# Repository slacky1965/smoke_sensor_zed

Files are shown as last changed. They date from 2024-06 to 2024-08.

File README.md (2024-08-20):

# Smoke Sensor Zigbee Telink TLSR8258 (E-BYTE E180-Z5812SP)

[Repository smoke_sensor_zed](https://github.com/slacky1965/smoke_sensor_zed)

* [Описание](#description)
* [Железо](#hardware)
* [Софт](#software)  
* [Принцип работы](#firmware)
* [Настройка](#settings)
* [Home Assistant](#home_assistant)
* [Alisa](#alisa)

---

## <a id="description">Описание</a>

* Сделано в виде дополнительной платы к заводскому пожарному дымовому извещателю [Рубеж ИП 212-50М2](https://yandex.ru/search?text=%D0%A0%D1%83%D0%B1%D0%B5%D0%B6+%D0%98%D0%9F+212-50%D0%9C2&lr=213).
* Изменяет статус ALARM1 в IAS при обнаружении дыма.
* Изменяет статус TAMPER в IAS при снятии извещателя с крепежной пластины.
* Посылает команду On-Off (Off-On или Toggle, в зависимости от выбранных настроек) при обнаружении дыма.
* Сохраняет настройки в энергонезависимой памяти модуля.
* Передает показания по сети Zigbee.
* Кластер On_Off имеет возможность напрямую подключаться к исполнительному устройству минуя координатор.
* Взаимодейстивие с "умными домами" через zigbee2mqtt.
* Первоначальная настройка происходит через web-интерфейс zigbee2mqtt.
* Подключиться к сети zigbee - удерживать кнопку на плате устройства более 5 секунд.
* Покинуть сеть zigbee - удерживать кнопку на плате устройства более 5 секунд.
* Сделать restart модуля - нажать кнопку 5 раз.
* При одиночном нажатии кнопки модуль просыпается и высылает отчеты.

---

## <a id="hardware">Железо</a>

В проекте используется модуль от компании E-BYTE на чипе TLSR8258F512ET32 - E180-Z5812SP.

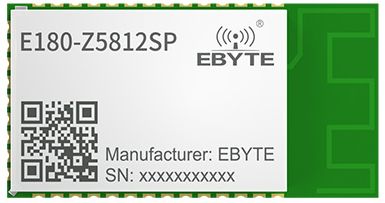
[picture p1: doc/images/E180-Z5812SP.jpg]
E-BYTE E180-Z5812SP


Испытывалось все на вот такой плате совместной разработки (спасибо [Олегу](https://t.me/Novgorod73))

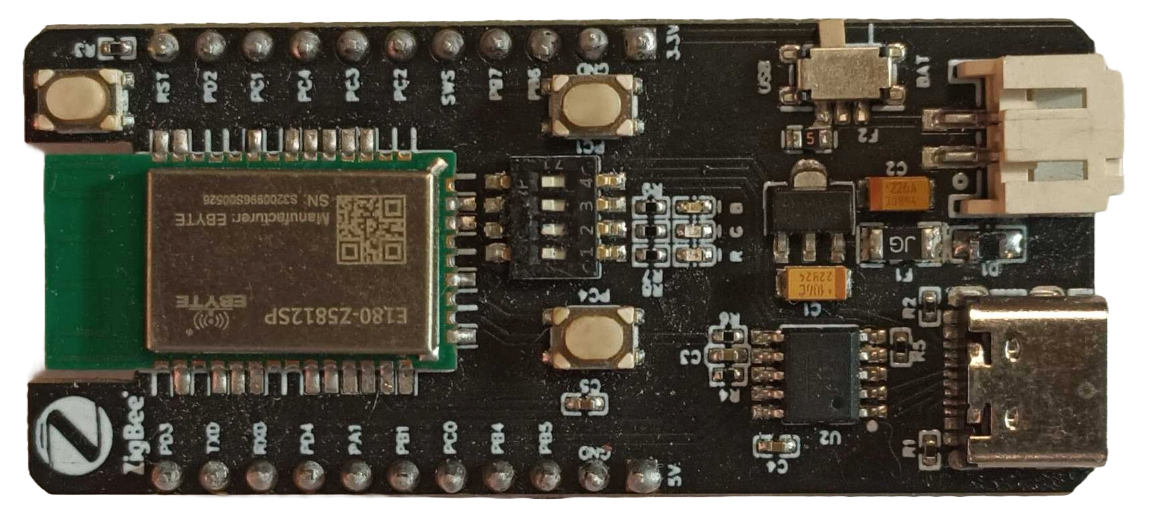
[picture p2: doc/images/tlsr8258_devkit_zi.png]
TLSR8258 devkit_zi


---

**Схема**

Схема изделия.

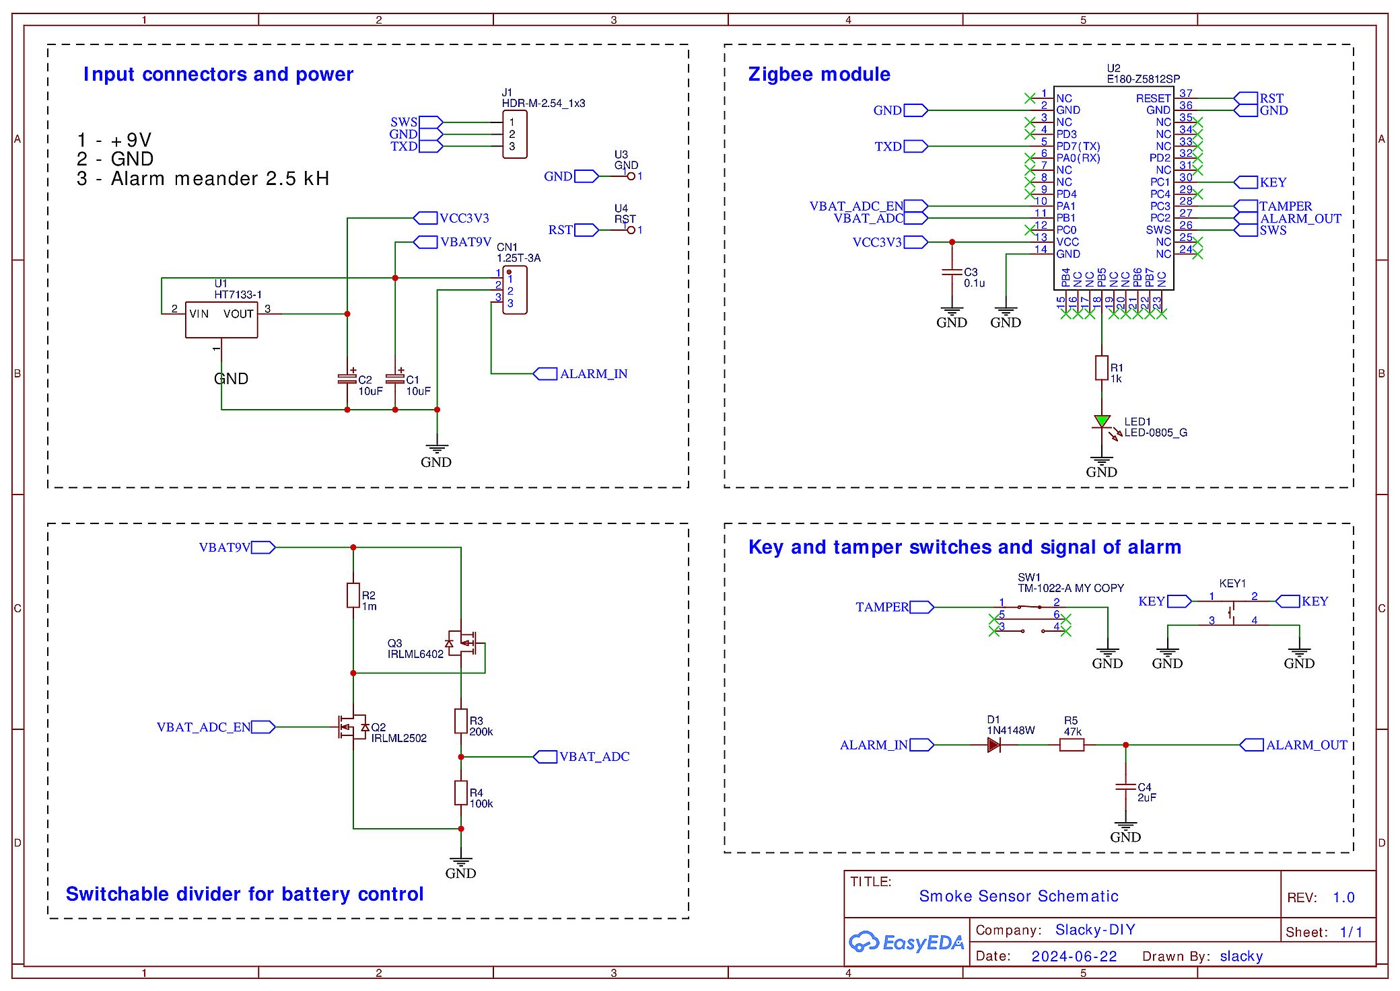
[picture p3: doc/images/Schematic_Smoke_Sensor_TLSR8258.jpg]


**Плата**

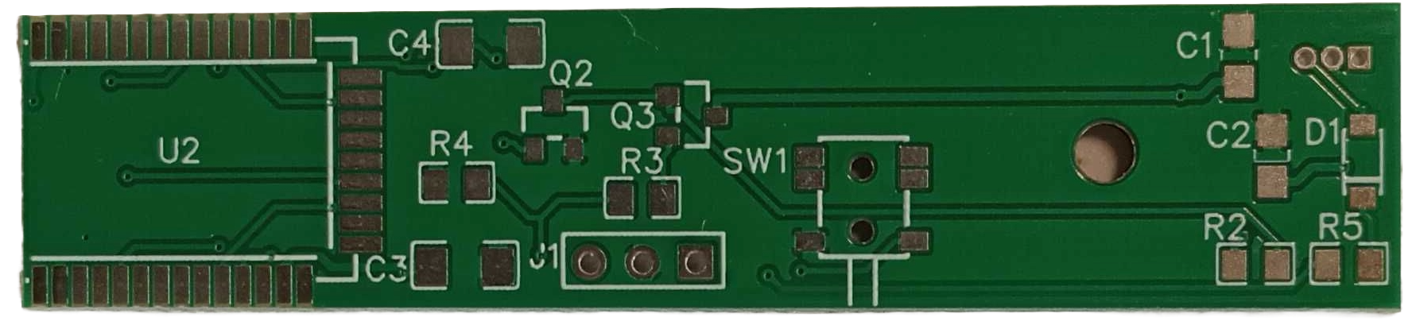
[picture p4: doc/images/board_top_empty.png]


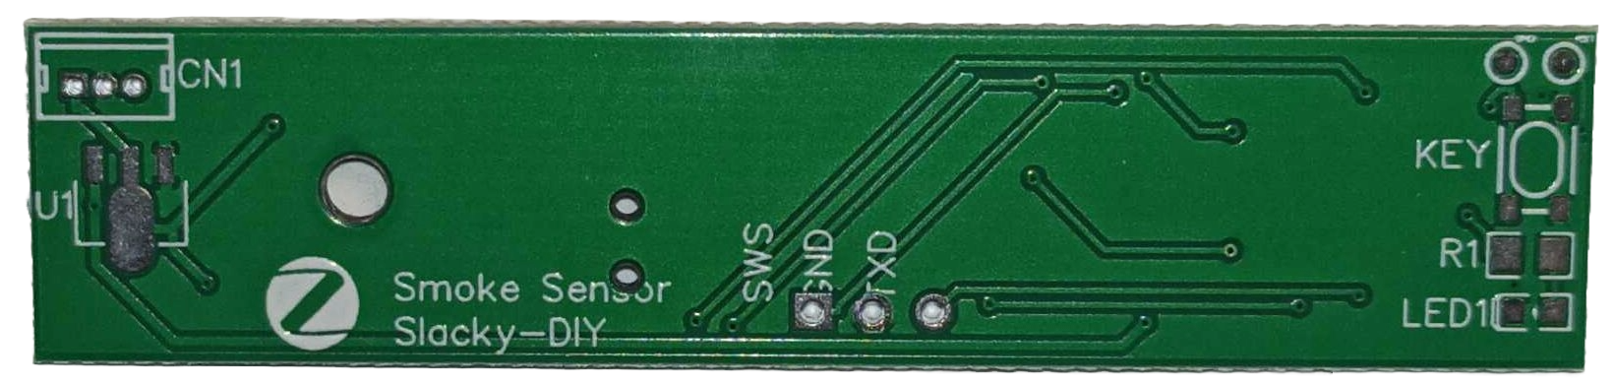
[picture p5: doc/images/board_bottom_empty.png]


На гребенку выведены следующие пины модуля

* SWS, GND - для заливки в модуль прошивки
* TXD-DBG - на всякий случай, вдруг кому-то пригодится для отладки.

[Ссылки на проект в easyeda](https://oshwlab.com/slacky/smoke_sensor_tlsr8258)

Детали, напечатанные на 3D принтере.

[Прокладка для платы](https://raw.githubusercontent.com/slacky1965/smoke_sensor_zed/main/doc/3D/Pad.STL)

[Кронштейн платы](https://raw.githubusercontent.com/slacky1965/smoke_sensor_zed/main/doc/3D/Support_new.STL)

Плата zigbee подключается к заводскому модулю следующим образом - 

* Красный провод (1 контакт разъема CN1) - к +9v - контакт 1 на плате извещателя.
* Черный провод (2 контакт разъема CN1) - к -9v (или земля) - контакт 2 на плате извещателя.
* Желтый провод (3 контакт раъема CN1) - контакт К1 на плате извещателя.

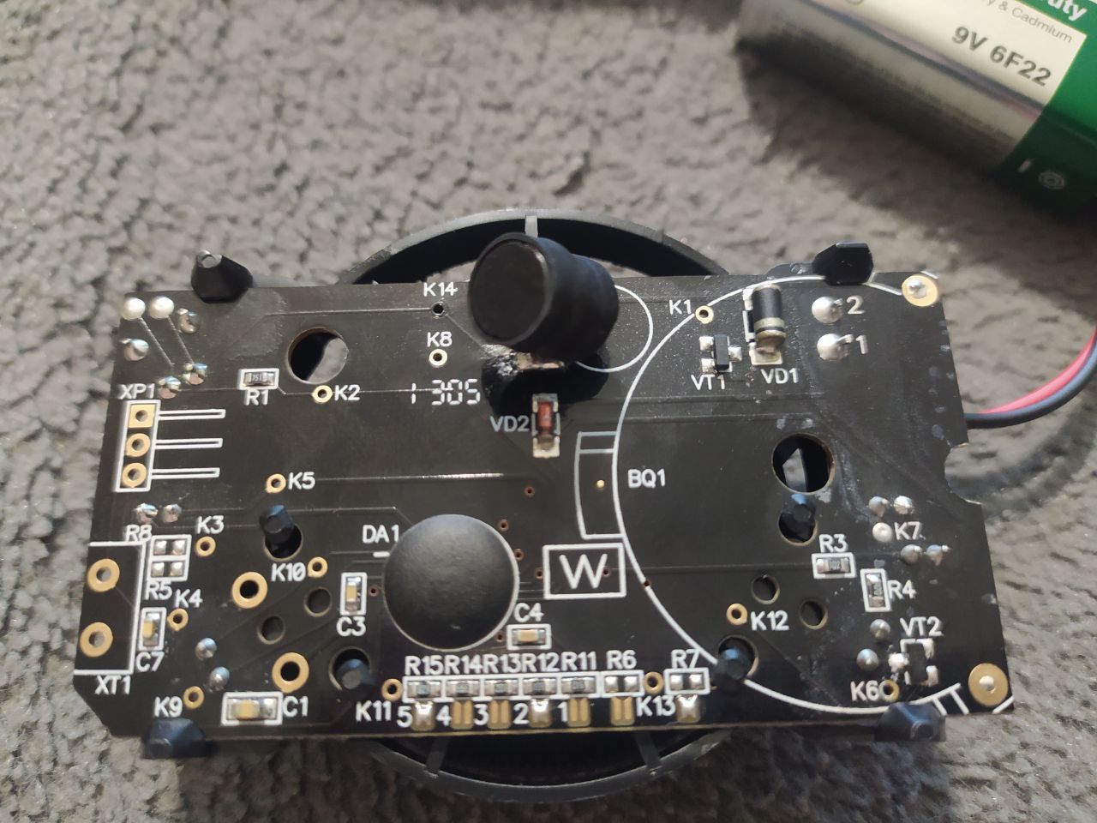
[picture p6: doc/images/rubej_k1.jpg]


**Готовое устройство**

Плата интегрированна в заводской пожарный дымовой извещатель Рубеж ИП 212-50М2.

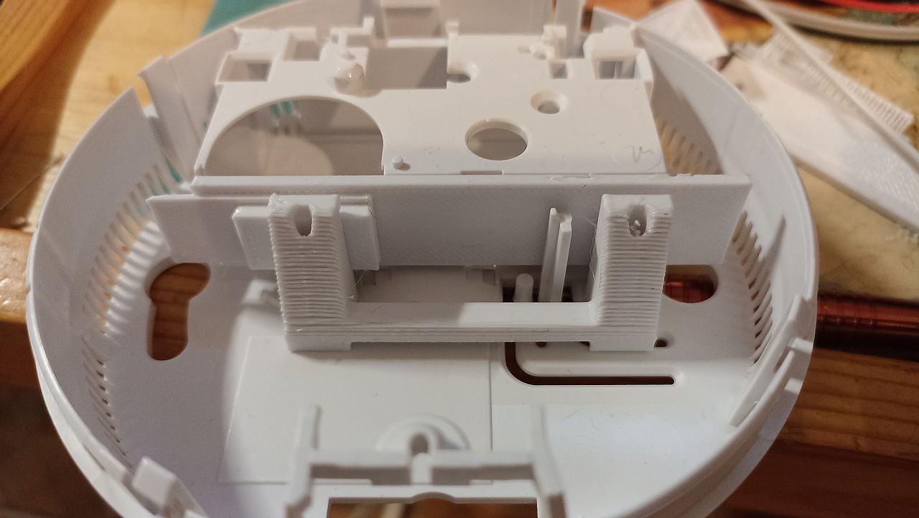
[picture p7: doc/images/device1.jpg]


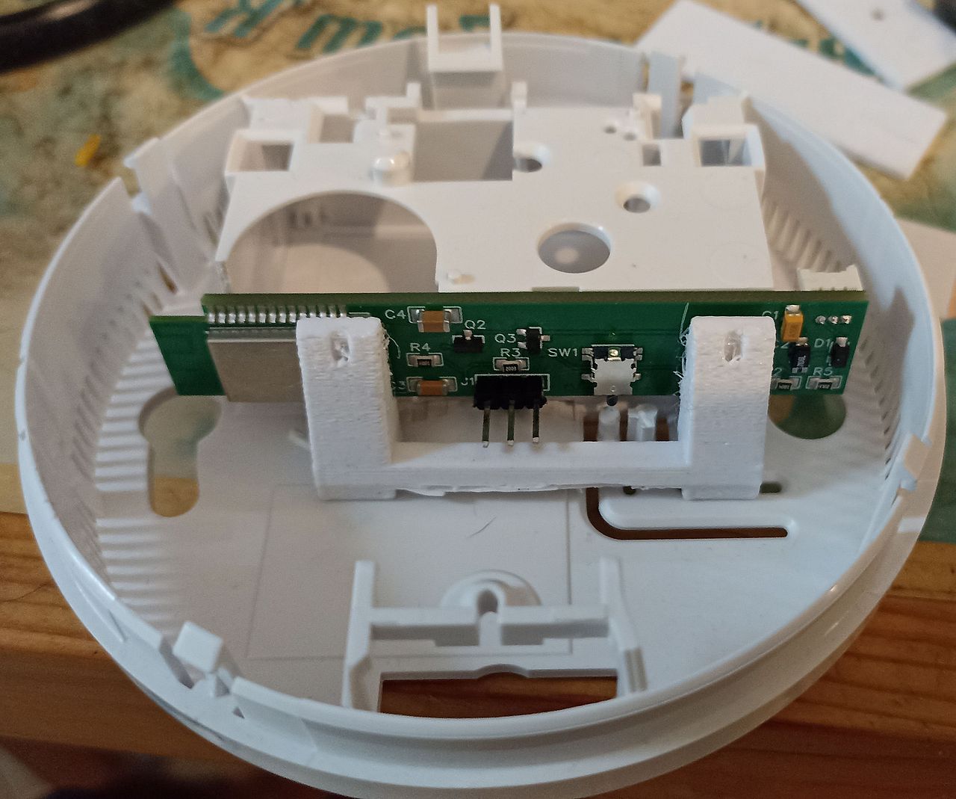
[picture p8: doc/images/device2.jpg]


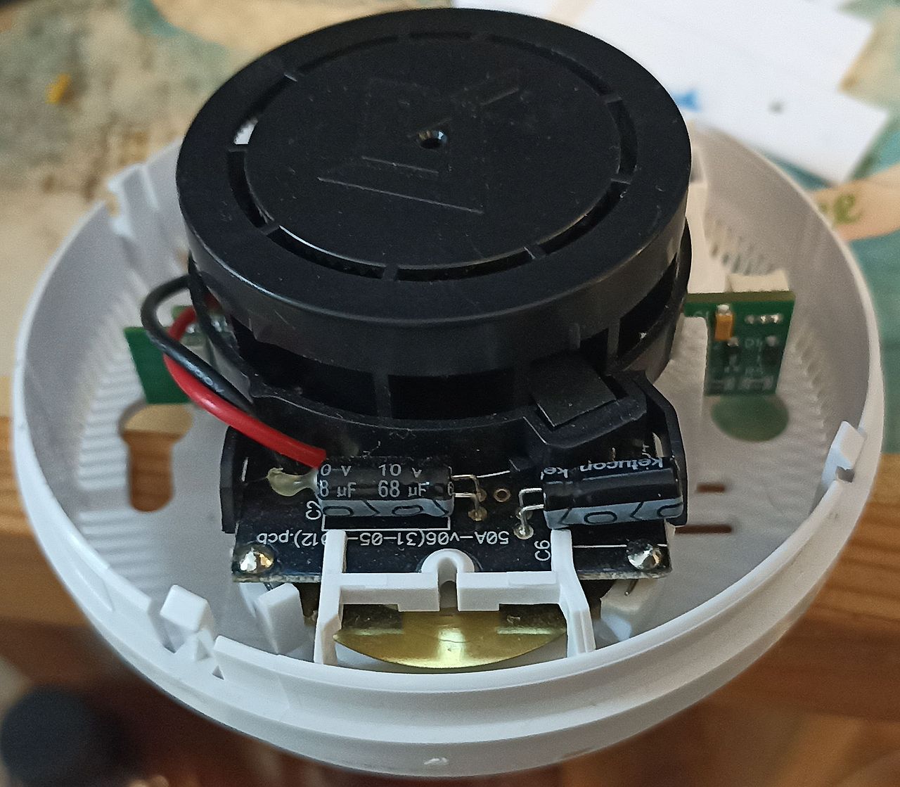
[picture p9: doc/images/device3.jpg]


---

## <a id="software">Софт</a>

Прошивок две. Изначально предполагалось, что микропереключатель на TAMPER будет нормально замкнутым. Но, что-то с ними проблема. И даже в лоте на Али, на котором указано, что это NC, китаец прислал NO. Потому прошивок две - одна под выключатель TAMPER NC, вторая под NO.

Нужную прошивку из [репозитория](https://github.com/slacky1965/smoke_sensor_zed) нужно залить в модуль с помощью [github.com/pvvx/TLSRPGM](https://github.com/pvvx/TLSRPGM) или оригинального программатора от Telink.

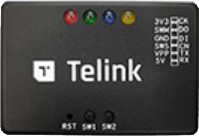
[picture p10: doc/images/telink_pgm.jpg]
Telink PGM


Как сделать недорогой программатор на базе модулей TB-03 или TB-04 можно почитать [тут](https://slacky1965.github.io/electricity_meter_zrd/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)

Используется последнее [SDK zigbee](http://wiki.telink-semi.cn/tools_and_sdk/Zigbee/Zigbee_SDK.zip) от Telink'а. Проект сформирован таким образом, что его можно собрать обычным make'ом как под Windows, в оболочке [Git Bash](https://git-scm.com/download/win), а также под Linux'ом (я проверял на Debian 11).

Как добавить проект в Eclipse можно почитать [тут](https://slacky1965.github.io/electricity_meter_zrd/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). Все точно так же, только для другого проекта.

Прошивка собрана по схеме, т.е. подключается файл платы `board_8258_diy.h`. Еще адаптирована плата devkit_zi. Для других вариантов придется самостоятельно редактировать файл нужной платы.

---

## <a id="firmware">Описание работы модуля</a>

В первый старт происходит попытка подключения к сети Zigbee. Если попытка удалась, модуль переходит в штатный режим работы. 

**Polling**
	
Первые 30 секунд модуль просыпается раз в 3 секунды. По истечению 30 секунд модуль засыпает на 5 минут. Через 5 минут опять просыпается раз в 3 секунды последующие 30 секунд. И опять засыпает на 5 минут. И так по кругу. Можно было сделать просыпание модуля раз в 5 минут, но zigbee2mqtt по умолчанию проверяет устройства на наличие в сети примерно раз в 10 минут. И начинает ругаться в логе, что устройство не найдено и выставляет статус offline. При такой неровной схеме эта проблема устраняется. Это конечно можно настроить в zigbee2mqtt, но я предпочел такой вариант. Сделать же период просыпания всегда раз в 3 секунды - необоснованное расходование ресурса батарейки.

**Reporting**

Модуль высылает 2 отчета для батарейки - процент заряда и напряжение. Периода отправки нет, отчет высылается по изменению. Изменение учитывает 0.1 вольт. Рабочим считается напряжение от 9.0 вольт до 7.2. Сам извещатель начиная с 7.2 вольта до 5.9 переходит в режим оповещения о разряде батареи - подает кратковременный однократный звуковой сигнал с периодомповторения от 60 до 65 секунд.

Напряжение на батарейке модуль проверяет один раз в час. Отчеты о состоянии батарейки (напряжение в мВ и остаточный ресурс в %) по изменению с шагом 0.1 вольт.

Также принудительно отчеты высылаются в течение 1 секунды, если нажать на кнопку прибора.

**Сетодиодная индикация режимов модуля**

Если модуль продолжительное время не моргает светодиодом (период более 5 минут), то он находится в режиме глубокого сна. Выйти из этого режима модуль может в двух случаях. Первый - если пользователь нажмет на кнопку. Второй - если сработает оригинальный извещатель на обнаружение дыма или если устройство снять с крепежной пластины.

1. Светодиод с периодичностью от 5 секунд до 5 минут мограет одной вспышкой - модуль находится в сети, работает в штатном режиме.
1. Светодиод с периодичностью 5 секунд моргает двумя вспышками - происходит OTA обновление прошивки.
1. Светодиод с периодичностью от 5 секунд до 5 минут моргает тремя вспышками - модуль не в сети - не был поключен, например вставили батарейки в устройство, но zigbee сети нет или активирован запрет на подключение; или был поключен, но в данный момент какие-то проблемы с сетью. В любом случае в таком режиме модуль проработает примерно 30 минут. Если за это время он не подключится к сети или не восстановит связь, то уйдет в глубокий сон. В этом режиме, чтобы связаться с модулем, нужно его разбудить, нажав на кнопку прибора.

---

**Zigbee Claster and Attribute**

В прошивке используется 1 endpoint, который содержит следующие кластеры

* Базовые кластеры.
* Кластер GEN_POWER_CFG, который отдает напряжение на батарейке и процент разряда.
* Кластер SS_IAS_ZONE, который собственно и сообщает о дыме, снятии устройства с крепежной пластины и разряженной батареи.
* Кластер GEN_ON_OFF, который посылает команду при обнаружении дыма на выбранное заранее устройство (прямой биндинг).
* Кластер ON_OFF_SWITCH_CFG, который позволяет выбрать действие кластера GEN_ON_OFF. Т.е. при обнаружении дыма возможно три варианта команды - On-Off, Off-On или Toggle.

---

## <a id="settings">Настройка</a>

Открываем на редактирование файл `configuration.yaml` от zigbee2mqtt. И добавляем в конец файла

		external_converters:
			- smoke_sensor.js
		ota:
			zigbee_ota_override_index_location: local_ota_index.json
		  
Файлы `smoke_sensor.js` и `local_ota_index.json` копируем из [репозитория проекта](https://github.com/slacky1965/smoke_sensor_zed/tree/main/zigbee2mqtt) туда же, где лежит `configuration.yaml` от zigbee2mqtt. Не забываем разрешить подключение новых устройств - `permit_join: true`. Перегружаем zigbee2mqtt. Проверяем его лог, что он запустился и нормально работает.

Далее, вставляем батарейки в устройство. Если питание было уже подано, то удерживаем кнопку на плате устройства (не на извещателе) более 5 секунд, до подтверждения сводиодом долгой вспышкой. Устройство должно подключиться к сети zigbee. Если подключение прошло удачно, то мы обнаружим наше устройство в zigbee2mqtt.

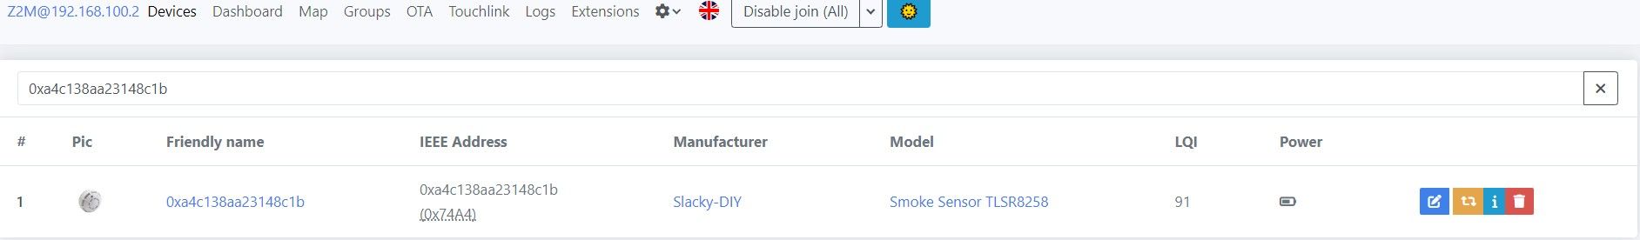
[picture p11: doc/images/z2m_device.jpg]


После того, как устройство подключилось к сети и zigbee2mqtt его обнаружил однократно нажать на кнопку на плате устройства (не на  извещателе), для первоначального заполнения всех велечин. 

После этого можно выбрать действие для кластера OnOff. Для этого нужно перейти в web-интерфейс zigbee2mqtt и зайти в раздел exposes.

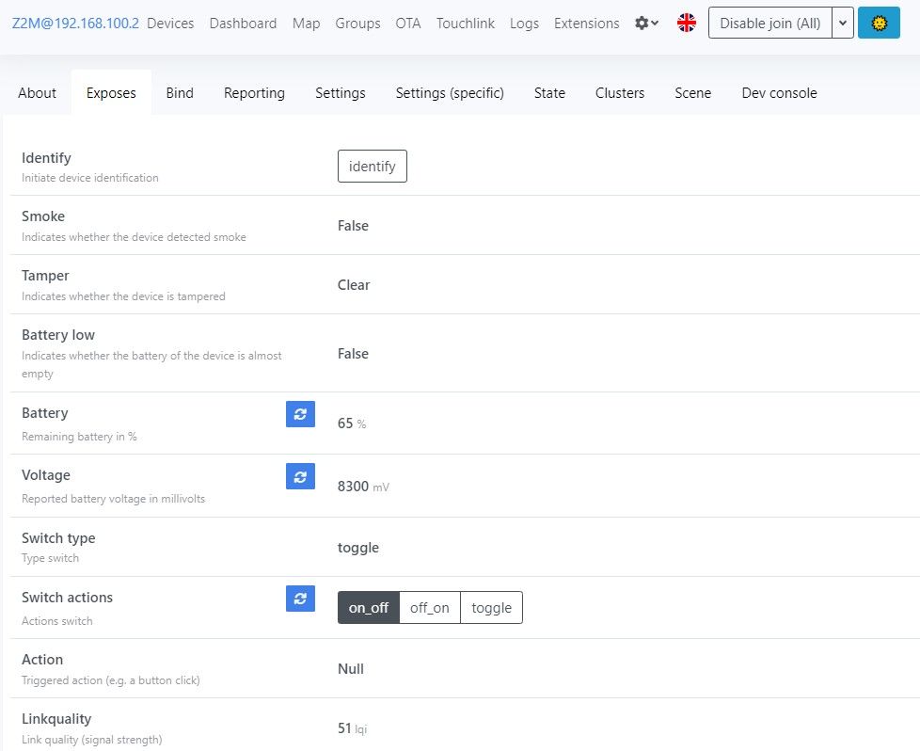
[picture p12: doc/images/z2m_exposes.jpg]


Затем нажать кнопку на устройстве, чтобы оно проснулось и приняло данные.

**Прямой биндинг**

При срабатывании датчика, т.е. обнаружении дыма, можно послать команду OnOff на какое-то устройство (если нужно).

Для настройки прямого биндинга заходим в раздел bind устройства.

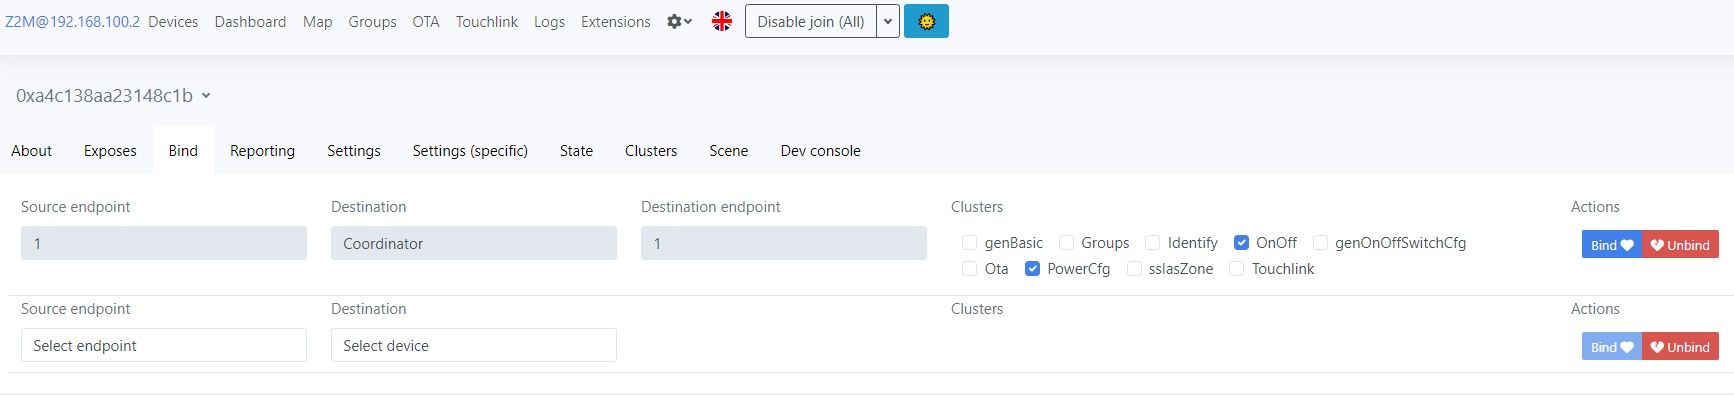
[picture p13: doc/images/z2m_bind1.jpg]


Снимаем все галочки, оствляем только на OnOff.

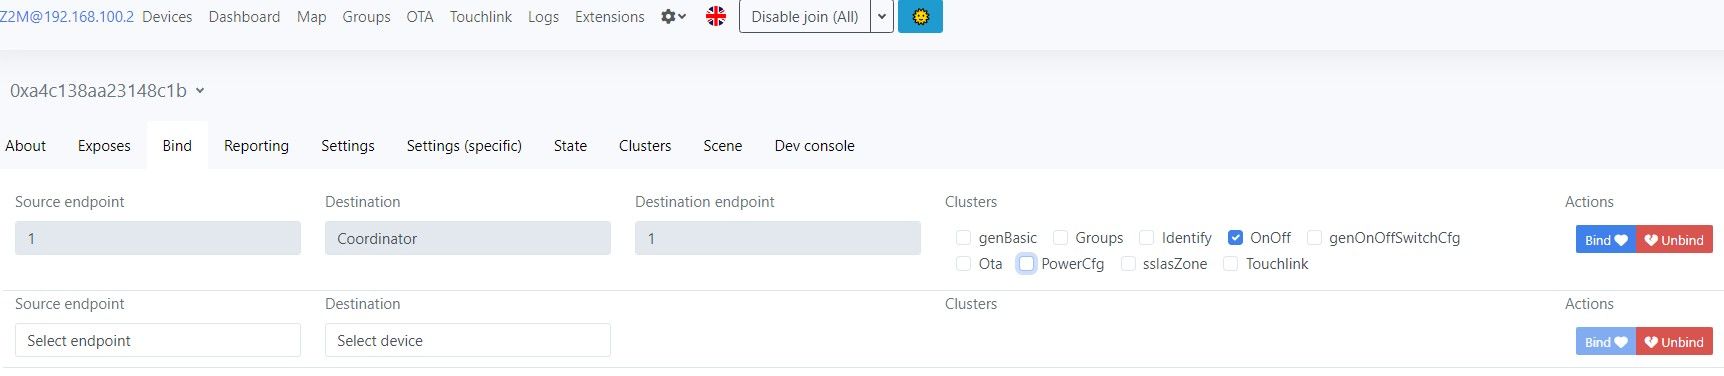
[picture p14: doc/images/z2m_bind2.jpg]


И жмем unbind, затем кнопку на плате (не на извещателе). Обновляем страницу, должно получиться вот так

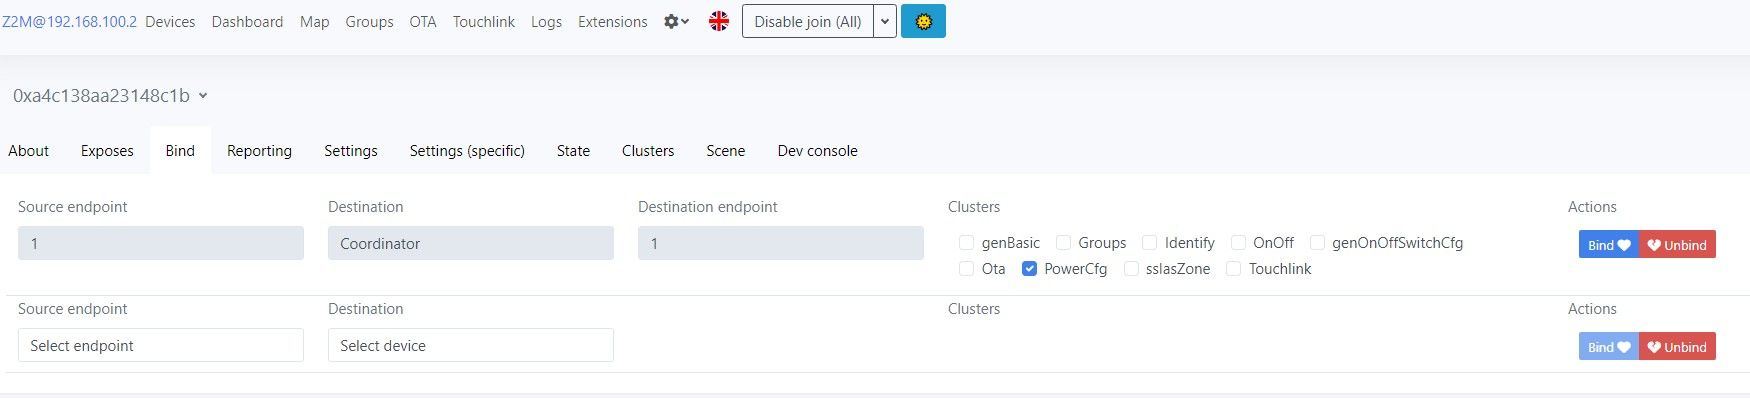
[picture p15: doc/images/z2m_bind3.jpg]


Далее в самой нижней ячейке выбираем устройство и endpoint на нем, на который хотим организвать прямую передачу команды OnOff. Ставим галочку на OnOff (выбранное устройство должно иметь такой кластер).

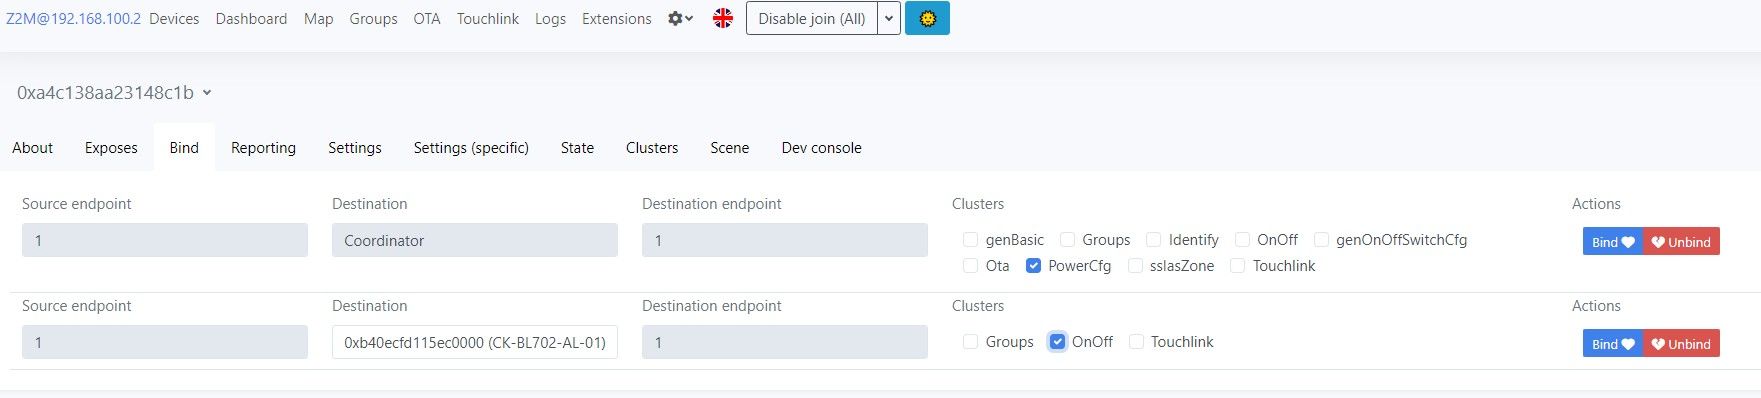
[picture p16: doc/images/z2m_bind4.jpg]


Жмем bind справа и нажимаем кнопку на плате (не на извещателе). После этого обновляем страницу. Должно получиться вот так

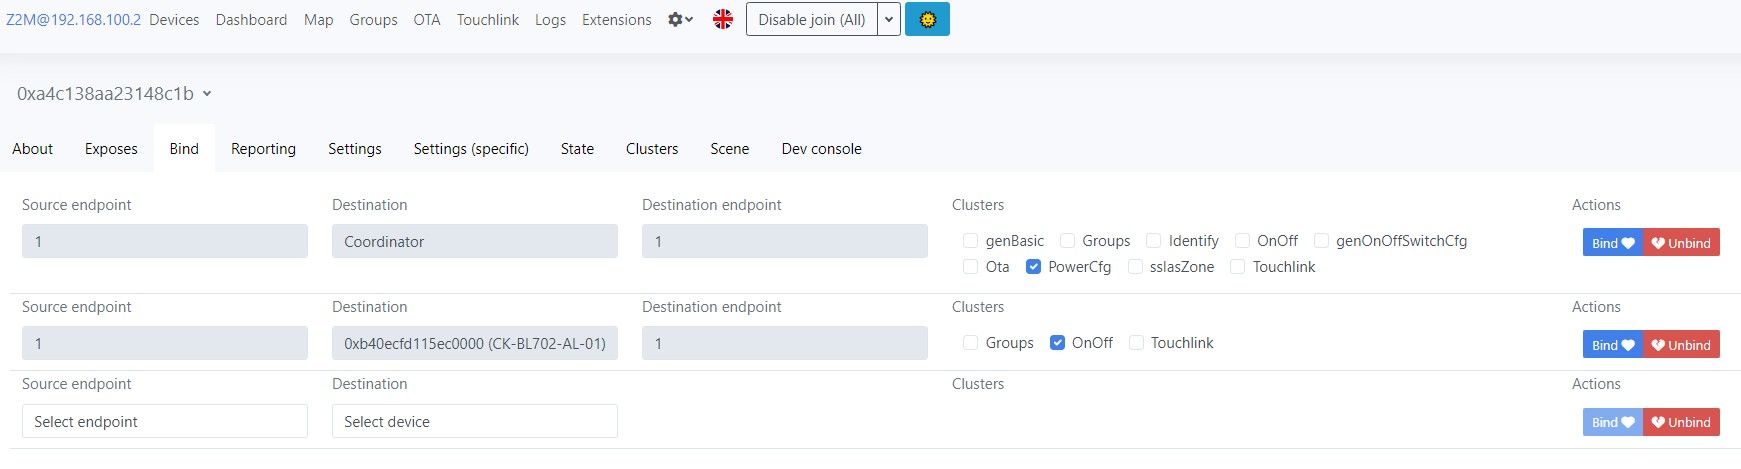
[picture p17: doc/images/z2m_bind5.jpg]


---

## OTA

Автоматического обновления в zigbee2mqtt для устройств, добавленных через конвертор, нет. Поэтому, если вышла новая версия, скачиваем обновленный файл прошивки для обновления OTA, например `6565-0204-13043001-smoke_sensor_zed.zigbee`. Переименовываем его в просто `smoke_sensor_zed.zigbee` и кладем его по относительному пути `zigbee2mgtt/images`. Перегружаем zigbee2mqtt. Идем во вкладку OTA. И кликаем на `Check for new updates` Если обновление принимается, то кнопка `Check for new updates` станет красной с надписью `Update device firmware`. Ее нужно кликнуть и обновление начнет загружаться (zigbee обновляется долго, что-то в районе 20 минут). 

---

## Потребление

Долгих испытаний в реальной работе пока не проводилось. С помощью ppk2 произведены замеры потребления дополнительной платы Zigbee.

**Штатный режим**

Среднее потребление за 15 минут 8,7 мкА.

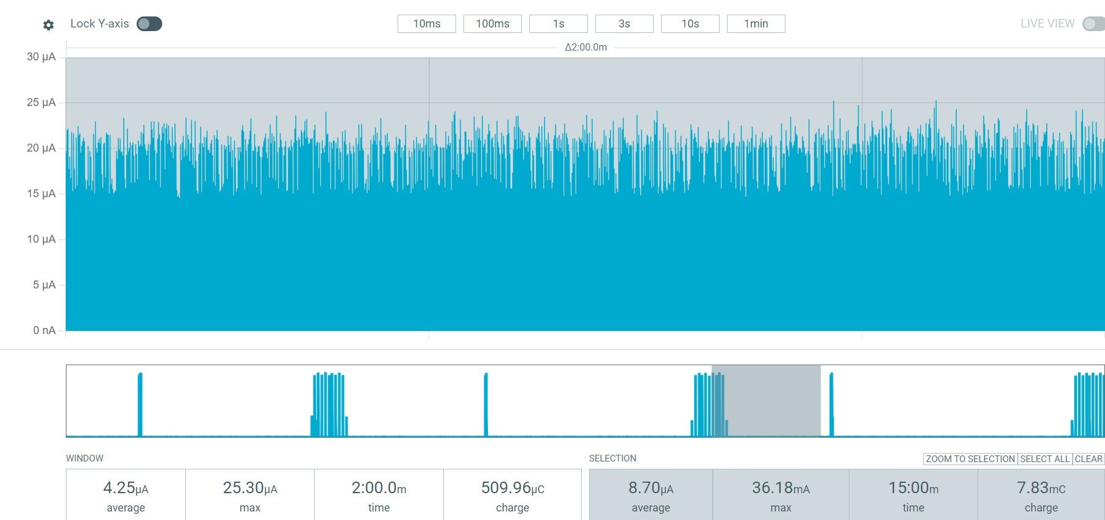
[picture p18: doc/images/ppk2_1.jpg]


**Модуль спит.**

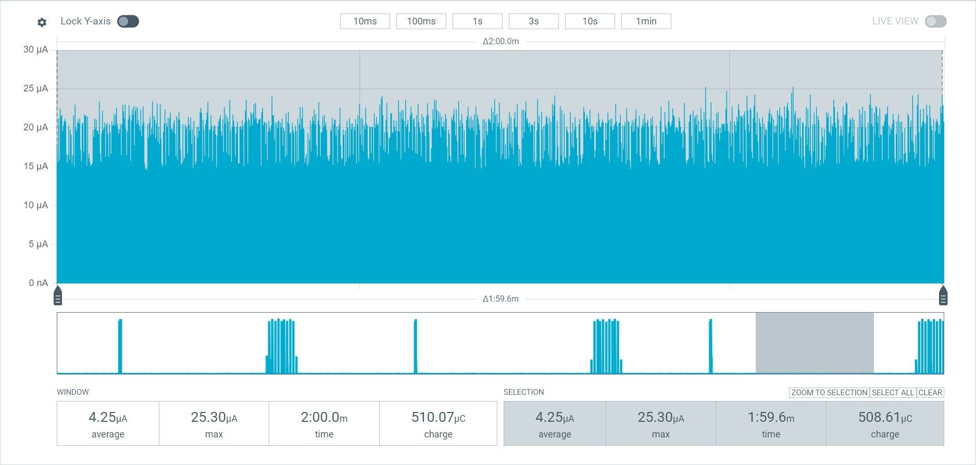
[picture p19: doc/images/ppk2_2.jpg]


---

## <a id="home_assistant">Home Assistant</a>

В Home Assistant устройство будет выглядеть так.

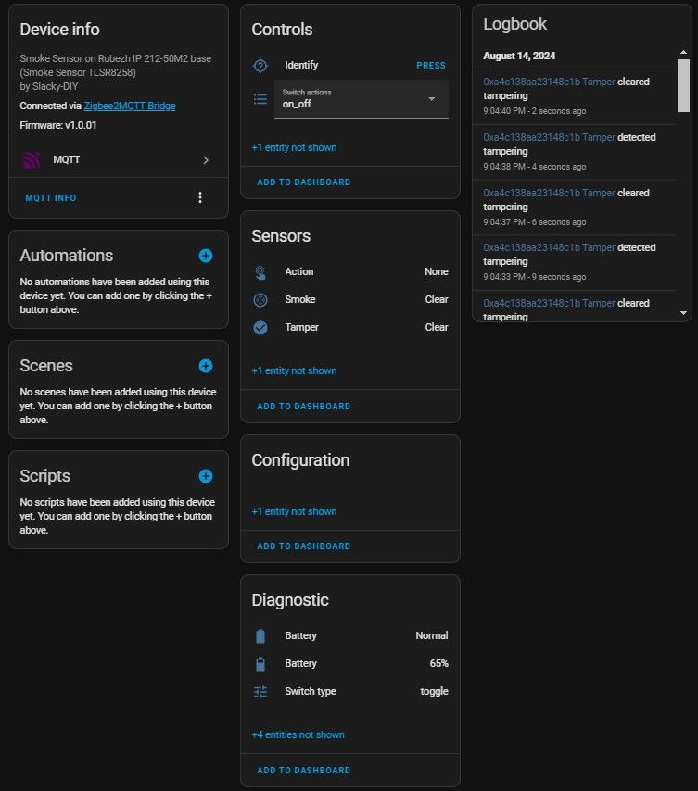
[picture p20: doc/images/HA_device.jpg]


---

## <a id="alisa">Alisa</a>

В Яндекс устройство будет выглядеть так.

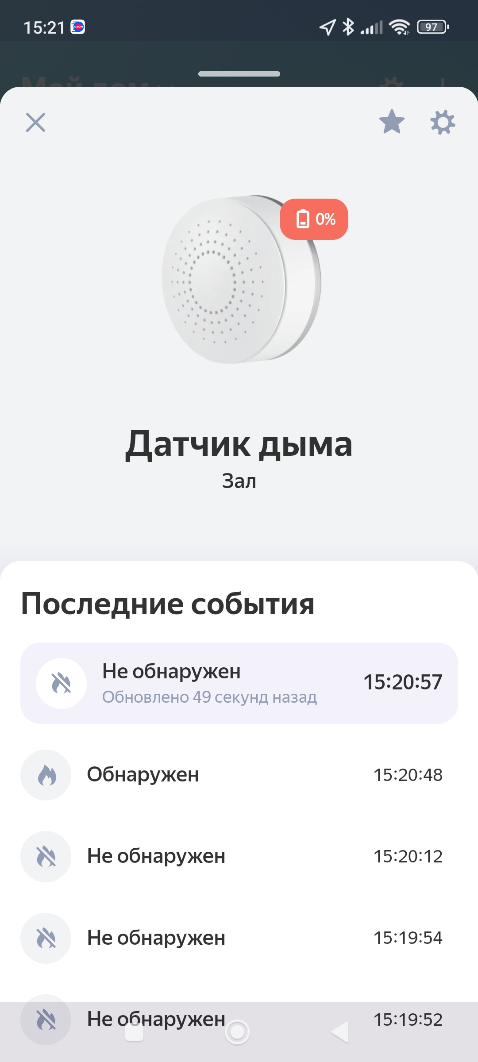
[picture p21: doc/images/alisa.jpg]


---

P.S. 

Устройство выполнено с максимальным соблюдением zigbee стандартов. Поэтому во многих системах он будет работать, если система поддерживает стандартные кластеры, такие как OnOff и IAS. Например z2m безо вских конверторов прекрасно определяет это устройство и поддерживает IAS полностью. Яндекс так же поддерживает IAS, но не полностью, он не видит TAMPER и разряд батареи (но процент заряда через другой кластер он прекрасно видит).

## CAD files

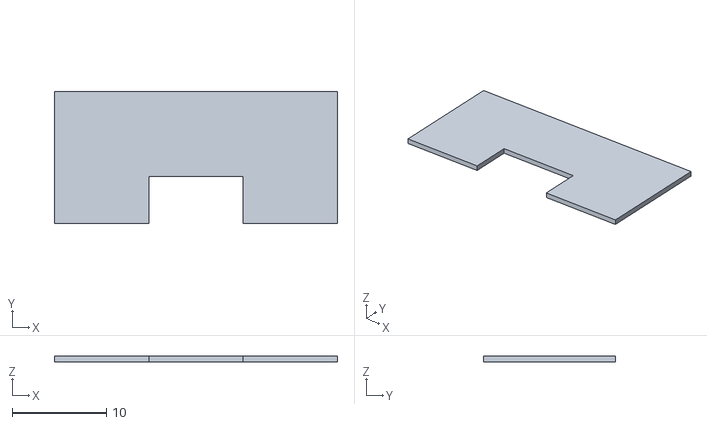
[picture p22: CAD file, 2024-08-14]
doc/3D/Pad.STL
30.0 x 14.0 x 0.6

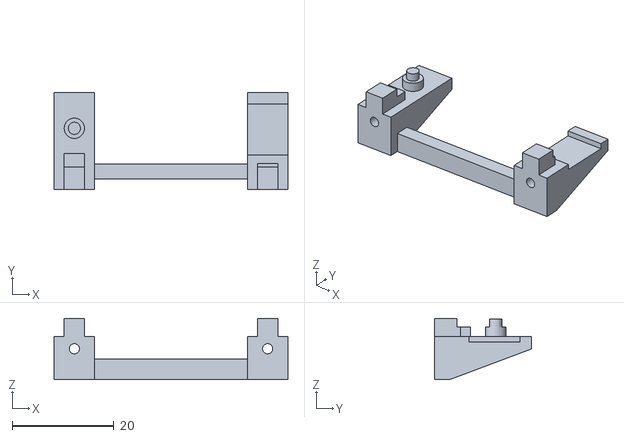
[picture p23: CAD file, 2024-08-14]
doc/3D/Support_new.STL
46.0 x 19.0 x 12.0

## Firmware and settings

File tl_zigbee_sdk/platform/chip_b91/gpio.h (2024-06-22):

/********************************************************************************************************
 * @file    gpio.h
 *
 * @brief   This is the header file for B91
 *
 * @author  Driver Group
 * @date    2019
 *
 * @par     Copyright (c) 2019, Telink Semiconductor (Shanghai) Co., Ltd. ("TELINK")
 *
 *          Licensed under the Apache License, Version 2.0 (the "License");
 *          you may not use this file except in compliance with the License.
 *          You may obtain a copy of the License at
 *
 *              http://www.apache.org/licenses/LICENSE-2.0
 *
 *          Unless required by applicable law or agreed to in writing, software
 *          distributed under the License is distributed on an "AS IS" BASIS,
 *          WITHOUT WARRANTIES OR CONDITIONS OF ANY KIND, either express or implied.
 *          See the License for the specific language governing permissions and
 *          limitations under the License.
 *
 *******************************************************************************************************/
/**	@page GPIO
 *
 *	Introduction
 *	===============
 *	B91 contain two six group gpio(A~F), total 44 gpio pin.
 *
 *	API Reference
 *	===============
 *	Header File: gpio.h
 */
#ifndef DRIVERS_GPIO_H_
#define DRIVERS_GPIO_H_


#include "lib/include/plic.h"
#include "analog.h"
#include "reg_include/gpio_reg.h"
/**********************************************************************************************************************
 *                                         global constants                                                           *
 *********************************************************************************************************************/

/**********************************************************************************************************************
 *                                           global macro                                                             *
 *********************************************************************************************************************/


/**********************************************************************************************************************
 *                                         global data type                                                           *
 *********************************************************************************************************************/
/**
 *  @brief  Define GPIO types
 *  @note	the following two points need to noticed when using PE5 port:
 *  		1. This pin is not recommend to use as wake-up source;
 *  		2. Since this pin is output function by default, even if it is configured with pull-up/pull-down retention,
 *  		when deep/deep Retention is invoked, it can't maintain high/low level and an abnormal level will occur.
 *  		Therefore, this pin can't be used in applications where a certain level state needs to be maintained all the time.
 *  		The PF group can only be used as an mspi pin and cannot be used as a wake-up source.
 */
typedef enum{
		GPIO_GROUPA    = 0x000,
		GPIO_GROUPB    = 0x100,
		GPIO_GROUPC    = 0x200,
		GPIO_GROUPD    = 0x300,
		GPIO_GROUPE    = 0x400,
		GPIO_GROUPF    = 0x500,
		GPIO_ALL       = 0x600,
	    GPIO_PA0 = GPIO_GROUPA | BIT(0),
		GPIO_PA1 = GPIO_GROUPA | BIT(1),
		GPIO_PA2 = GPIO_GROUPA | BIT(2),
		GPIO_PA3 = GPIO_GROUPA | BIT(3),
		GPIO_PA4 = GPIO_GROUPA | BIT(4),
		GPIO_PA5 = GPIO_GROUPA | BIT(5),GPIO_DM=GPIO_PA5,
		GPIO_PA6 = GPIO_GROUPA | BIT(6),GPIO_DP=GPIO_PA6,
		GPIO_PA7 = GPIO_GROUPA | BIT(7),GPIO_SWS=GPIO_PA7,
		GPIOA_ALL = GPIO_GROUPA | 0x00ff,

		GPIO_PB0 = GPIO_GROUPB | BIT(0),
		GPIO_PB1 = GPIO_GROUPB | BIT(1),
		GPIO_PB2 = GPIO_GROUPB | BIT(2),
		GPIO_PB3 = GPIO_GROUPB | BIT(3),
		GPIO_PB4 = GPIO_GROUPB | BIT(4),
		GPIO_PB5 = GPIO_GROUPB | BIT(5),
		GPIO_PB6 = GPIO_GROUPB | BIT(6),
		GPIO_PB7 = GPIO_GROUPB | BIT(7),

		GPIO_PC0 = GPIO_GROUPC | BIT(0),GPIO_SWM=GPIO_PC0,
		GPIO_PC1 = GPIO_GROUPC | BIT(1),
		GPIO_PC2 = GPIO_GROUPC | BIT(2),
		GPIO_PC3 = GPIO_GROUPC | BIT(3),
		GPIO_PC4 = GPIO_GROUPC | BIT(4),
		GPIO_PC5 = GPIO_GROUPC | BIT(5),
		GPIO_PC6 = GPIO_GROUPC | BIT(6),
		GPIO_PC7 = GPIO_GROUPC | BIT(7),
		GPIOC_ALL = GPIO_GROUPC | 0x00ff,

		GPIO_PD0 = GPIO_GROUPD | BIT(0),
		GPIO_PD1 = GPIO_GROUPD | BIT(1),
		GPIO_PD2 = GPIO_GROUPD | BIT(2),
		GPIO_PD3 = GPIO_GROUPD | BIT(3),
		GPIO_PD4 = GPIO_GROUPD | BIT(4),
		GPIO_PD5 = GPIO_GROUPD | BIT(5),
		GPIO_PD6 = GPIO_GROUPD | BIT(6),
		GPIO_PD7 = GPIO_GROUPD | BIT(7),

		GPIO_PE0 = GPIO_GROUPE | BIT(0),
		GPIO_PE1 = GPIO_GROUPE | BIT(1),
		GPIO_PE2 = GPIO_GROUPE | BIT(2),
		GPIO_PE3 = GPIO_GROUPE | BIT(3),
		GPIO_PE4 = GPIO_GROUPE | BIT(4),
		GPIO_PE5 = GPIO_GROUPE | BIT(5),
		GPIO_PE6 = GPIO_GROUPE | BIT(6),
		GPIO_PE7 = GPIO_GROUPE | BIT(7),
		GPIOE_ALL = GPIO_GROUPE | 0x00ff,
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

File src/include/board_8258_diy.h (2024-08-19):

#ifndef SRC_INCLUDE_BOARD_8258_DIY_H_
#define SRC_INCLUDE_BOARD_8258_DIY_H_

/************************* Configure SMOKE GPIO **************************************/
#define ALARM_GPIO              GPIO_PC2
#define PC2_FUNC                AS_GPIO
#define PC2_OUTPUT_ENABLE       OFF
#define PC2_INPUT_ENABLE        ON
#define PULL_WAKEUP_SRC_PC2     PM_PIN_PULLDOWN_100K

#define TAMPER_GPIO             GPIO_PC3
#define PC3_FUNC                AS_GPIO
#define PC3_OUTPUT_ENABLE       OFF
#define PC3_INPUT_ENABLE        ON
#define PULL_WAKEUP_SRC_PC3     PM_PIN_PULLUP_1M

/* tamper switch type 1 - NC, 0 - NO */
#ifndef TAMPER_SWITCH_NC
#define TAMPER_SWITCH_NC        0
#endif


/********************* Configure External Battery GPIO ******************************/
#define VOLTAGE_DETECT_PIN      GPIO_PB1
#define VOLTAGE_DIVISOR_PIN_EN  GPIO_PA1
#define PA1_FUNC                AS_GPIO
#define PA1_OUTPUT_ENABLE       ON
#define PA1_INPUT_ENABLE        OFF
#define PULL_WAKEUP_SRC_PA1     PM_PIN_PULLDOWN_100K

/************************* Configure KEY GPIO ***************************************/
#define MAX_BUTTON_NUM  1

#define BUTTON1                 GPIO_PC1
#define PC1_FUNC                AS_GPIO
#define PC1_OUTPUT_ENABLE       OFF
#define PC1_INPUT_ENABLE        ON
#define PULL_WAKEUP_SRC_PC1     PM_PIN_PULLUP_1M

//#define PM_WAKEUP_LEVEL         PM_WAKEUP_LEVEL_LOW
//#define PM_WAKEUP_LEVEL_ALARM   PM_WAKEUP_LEVEL_HIGH

enum {
    VK_SW1 = 0x01,
};

#define KB_MAP_NORMAL   {\
        {VK_SW1,}}

#define KB_MAP_NUM      KB_MAP_NORMAL
#define KB_MAP_FN       KB_MAP_NORMAL

#define KB_DRIVE_PINS  {NULL }
#define KB_SCAN_PINS   {BUTTON1}


/**************************** Configure UART ***************************************
*    UART_TX_PA2 = GPIO_PA2,
*    UART_TX_PB1 = GPIO_PB1,
*    UART_TX_PC2 = GPIO_PC2,
*    UART_TX_PD0 = GPIO_PD0,
*    UART_TX_PD3 = GPIO_PD3,
*    UART_TX_PD7 = GPIO_PD7,
*    UART_RX_PA0 = GPIO_PA0,
*    UART_RX_PB0 = GPIO_PB0,
*    UART_RX_PB7 = GPIO_PB7,
*    UART_RX_PC3 = GPIO_PC3,
*    UART_RX_PC5 = GPIO_PC5,
*    UART_RX_PD6 = GPIO_PD6,
*/

#if UART_PRINTF_MODE
#define DEBUG_INFO_TX_PIN       UART_TX_PD7//print
#define BAUDRATE                115200
#endif /* UART_PRINTF_MODE */

/**************************** Configure LED ******************************************/

#define LED1                    GPIO_PB5
#define PB5_FUNC                AS_GPIO
#define PB5_OUTPUT_ENABLE       ON
#define PB5_INPUT_ENABLE        OFF

/**************************************************************************************/

#endif /* SRC_INCLUDE_BOARD_8258_DIY_H_ */

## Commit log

2024-08-20 new voltage factor
2024-08-20 new battery_init
